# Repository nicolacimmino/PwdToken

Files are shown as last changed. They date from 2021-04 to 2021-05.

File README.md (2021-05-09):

# PwdToken

## Introduction

This started as a hardware implementation of a piece of paper with your password on it and, in some respect, it sill is. So use it with judgment! I toyed at first with the idea mostly of having something to type the WiFi password on new devices or for guests.

Once the novelty of the first quick implementation wore out, I started to wonder how I could make this at least reasonably secure. In its current incarnation the PwdToken offers the following features:

* Runs on a Digispark Digistump (or similart ATTiny85 device)
* Requires only 2 buttons to be soldered to the board
* Stores up to 4 passwords
* Emulates a USB keyboard and types the password
* Easy 2 buttons operation

Security features:
* Unlock password by morse keypad (optional)
* Unlock PIN by binary keypad (optional)
* Mechanism to validate count of boots and passwords recoveries (tamper/usage detection)

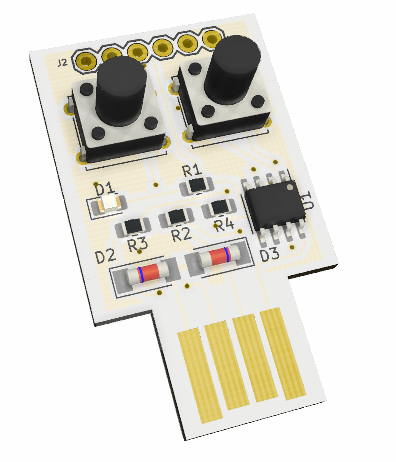
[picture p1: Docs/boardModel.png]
board


# Table of contents

[**Safety**](#safety)

&nbsp;&nbsp;&nbsp;&nbsp;[What makes this reasonably safe](#what-makes-this-reasonably-safe)<br>
&nbsp;&nbsp;&nbsp;&nbsp;[Known vulnerabilities](#known-vulnerabilities)<br>
&nbsp;&nbsp;&nbsp;&nbsp;[What can I do to make it safer?](#what-can-i-do-to-make-it-safer)<br>

[**Build one**](#build-one)

&nbsp;&nbsp;&nbsp;&nbsp;[The hardware](#the-hardware)<br>
&nbsp;&nbsp;&nbsp;&nbsp;[Special bootloader](#special-bootloader-optional)<br>

[**Usage**](#usage)

&nbsp;&nbsp;&nbsp;&nbsp;[Store passwords](#store-passwords)<br>
&nbsp;&nbsp;&nbsp;&nbsp;[Retrieve a password](#retrieve-a-password)<br>
&nbsp;&nbsp;&nbsp;&nbsp;[Getting the token banner](#getting-the-token-banner)<br>

[**Encase it**](#encase-it)

## Safety

Is it safe?

TLDR: **NO**

Long story. It can be reasonably safe depending on your use case. If you often need to log in on computers that are not yours and on which you can't run a password manager, this could be a viable option, especially if the alternative is to use a weak password that you can remember. At least you have shifted the extent of the potential attackers from anyone on the the Internet to anyone who can gain access to your token. 

### What makes this reasonably safe?

The passwords are stored in the actual application, and not in the data EEPROM. This means that if anyone attempts to replace the application with one that just exfiltrates the passwords then the passwords will actually be wiped.

There's a meachanism (optional) to keep track of the boots count and amount of times passwords have been retrieved. A command line application can be used to validate these against a manifest containing, among other information, a shared secret. While this doesn't prevent password theft it makes tampering evident.

### Known vulnerabilities

**do I need to say it? this is bound to be an incomplete list**

* An attacker could craft an .hex file that doesn't override the portion of code with the passwords and exfiltrates them. For this attack to be successfull it would be enough to compromise a host machine and have a microncleus uploader waiting for a device all the time (also the uploader would need to be made not to erase all memory before programming but just to send a page full of 0xFF on the part to override). This is an issue only if the stock micronucleus bootloader is used. This project provides a re-configured version of the bootloader that doesn't start unless button B (P0) is held. Additionally the special bootloader always erases user program on entry which prevents this attack also if the attacker has physical access to the token (assuming he cannot re-program it with an AVR programmer, ie that the board is encased in epoxy and only USB pins are accessible).

* An attacker could connect an AVR programmer and dump the application or replace the bootloader with one that exfiltrates the passwords. This is possible only if the attacker has physical access to the token. This can be mitigated by enclosing the devive in epoxy so that only the USB pins are accessible. While the attacker could still possibly re-program it, this would require access to the device for a longer time and the tampering would be evident.

* Because of the way the password lock works (just waits until the right PIN/Password is entered), and because the onboard LED signals the fact the token is locked, an attacker could build a device that brute forces the PIN/Password quite easily. One possible mitigating action would be to add a max errors after which the device wipes itself. Also in this case physical access to the device is needed to carry out this attack so epoxying the board would suffice.

### What can I do to make it safer?

* Make use of the provided modified bootloader so the device cannot be re-programmed without physical access to it and, even if bootloader is entered, the program is wiped already
* Don't store the full password, use a Horcrux (in a nutshell, make your password something like `fsnf23m!abcSomethingIOnlyKnow` and only store the `fsnf23m!abc` part to then type the reminder)
* Don't leave the token unattended and keep track of your tokens so you can immediately reset the passwords if one is missing
* Encase the device in epoxy so only the USB pins are accessible. This prevents PIN brute force automation as well as bootloaded replacement.

## Build one

### The hardware

If you want to just give this a spin a quick way to start is with a Digispark Digistump or another ATTiny85 board with USB. You will need to add two push buttons. Connect them between P0 and P2 and ground. See photo for one of my prototypes.

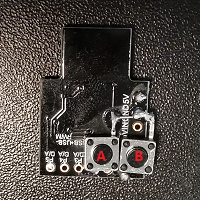
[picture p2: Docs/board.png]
board


If you feel instead like wire wrapping and you have a DIP ATTiny85 you can follow this schematic. J2 is needed only if you need to burn a bootloader, if your ATTiny is already loaded with a bootloader you can omit it.

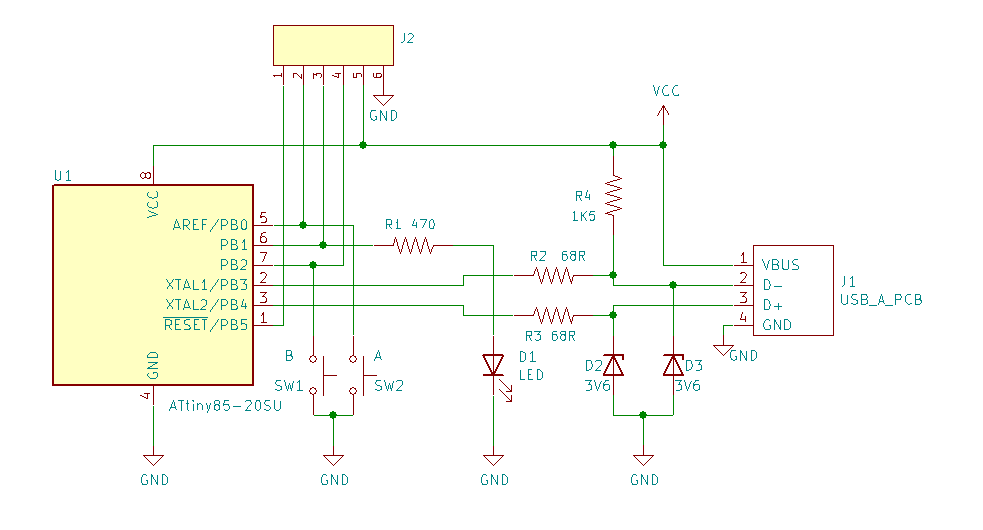
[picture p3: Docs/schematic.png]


Alternatively, if you really want to go serious you can find all the Kicad files for the board in the `Board` folder.

### Special bootloader (optional)

You can replace the standard "micronucleus" bootloader that comes with the Digistump and other ATTiny borards, with a version that doesn't wait in the bootloader by default when started. This makes your PwdToken immediately available when plugging it. Once you uploaded the re-configured bootloader you will need to pull P0 low (press button B before inserting the board in the USB port). To carry out this step you will need an ISP. I tested this with a USBASP. Others shouldn't be that much different but you will need to tweak the actual programming command. 

If you choose to skip this step the downside will be that once you plug your board in the USB port you will need to wait about 6 seconds for the bootloader to give up and your program to start.

Another tweak to the bootloader that can make the device safer, is to enable deletion of the user program as soon as it's  the bootloader is entered. In this way it won't be possible in any way to attempt to exfiltrate the passwords through USB. 

**NOTE**: it will be still possible to get to them if the attacker has access to all pins (device not epoxied) as he will be able to replace the bootloader.

See the readme in the "mirconucleus" folder below for instructions on building and flashing the special bootloader.

## Usage

### Store passwords 

**Without manifest**

If you wish to just set up passwords and don't want to generate a manifest to verify the integrity of the token (and to have proof the token has not been used) follow these simple steps:

* Copy `secrets_example.h` to `secrets.h` (this last is .gitignore:d so you don't risk to push your passwords!)
* Edit `secrets.h` and set your passwords and unlock password/pin if desired
* Edit `options.h` and set options as needed 
* Build and upload

**With manifest**

If you choose to generate a manifest for the token you will be able at a later time to verify that the token has not been tampered with and you will be able to determine if and how many times it has been booted and passwords have been retrieved.

To generate a manifest use the command line utility under `CommandLineTool\bin`:

* Run `pwdtoken gen`
* Choose a label for the token
* Choose a secret
* The utility will generate a manifest and store in clipboard
* Store the manifest somewhere safe (eg a password manager)
* The utility will also generate a `secrets.h` file
* Edit `secrets.h` and set your passwords and unlock password/pin if desired (don't change the OTP secret or the label though or you will invalidate the manifest!)
* Edit `options.h` and set options as needed 
* Build and upload

## Retrieve a Password

**note** the token emulates a standard US layout keyboard. You will need to make sure your keyboard layout matches, especially if your password contains symbols that might be mapped to different keys.

* Insert the token in a USB port and wait until the onboard red LED is solid red (or flashing slowly if you choose not to have an unlock PIN/Password)
* Type your PIN/Password if needed
* Once unlocked the onboard red LED will start to flash. The flashes count indicates the selected password
* Press repeatedly button B until the desired password is selected
* Focus on the application/field in which you need to type the password
* Press and hold A for more than 2 seconds and the password will by typed

## Getting the token banner

The token banner is a piece of formatted text that contains non-confidential information and can be used to validate the boot counts as well as to make sure your keyboard layout is correct. The banner is always accessible without unlocking the token. To print the banner follow these steps:

* Open a text editor and ensure it's in focus
* Insert the token while keeping button A pressed (make sure you don't confuse A with B if you have the special bootloader or your passwords will be lost!)
* Release the button as soon as the banner is starting to appear

A banner looks like this:

````
----------- begin -----------

; PwdToken 0.01-B
; Built Apr 14 2021 07:27:29
; Keyboard Layout US
; Hash Backslash: £ #
LBL: TST002
CBO: 3
CRE: 0
OTP: 3158792869

------------ end ------------
````

You can use the `; Hash Backslash: # \` line to validate that the current keyboard layout is correct. Most of the rest of the information in the banner is data needed by the command line utility to validate the boot and password retrieval counters.

## Encase it

In the `case` folder you will find a FreeCad project for a simple case for the token. This is suitable to be filled with epoxy to prevent (easy) access to the passwords through the ISP interface. There's no provision for screws or other fixing mechanisms, the two halves of the shell are meant to be glued together once the epoxy is set.

Top             |  Bottom    | Assembled
:-------------------------:|:-------------------------:|:-------------------------:
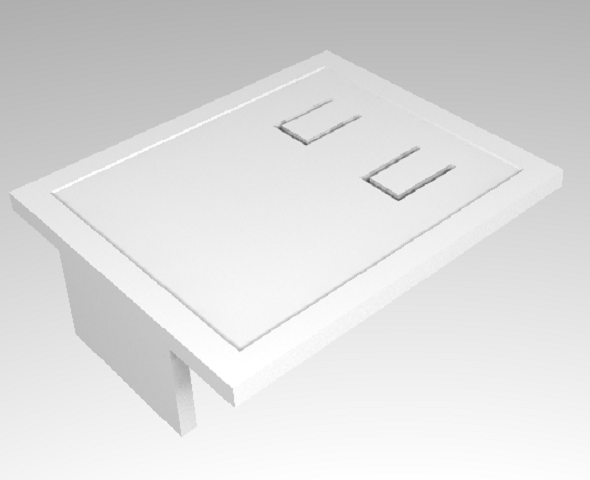
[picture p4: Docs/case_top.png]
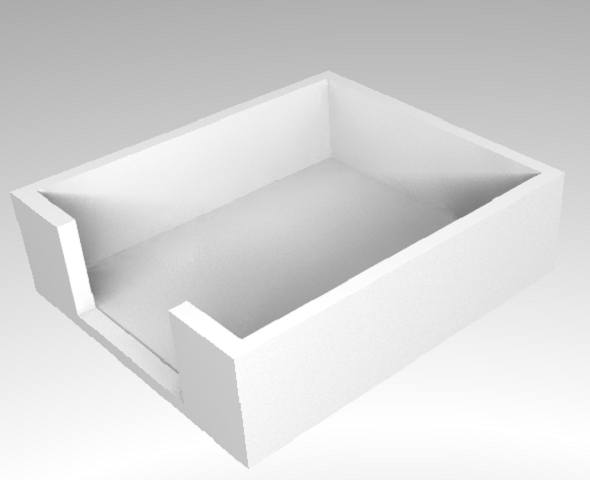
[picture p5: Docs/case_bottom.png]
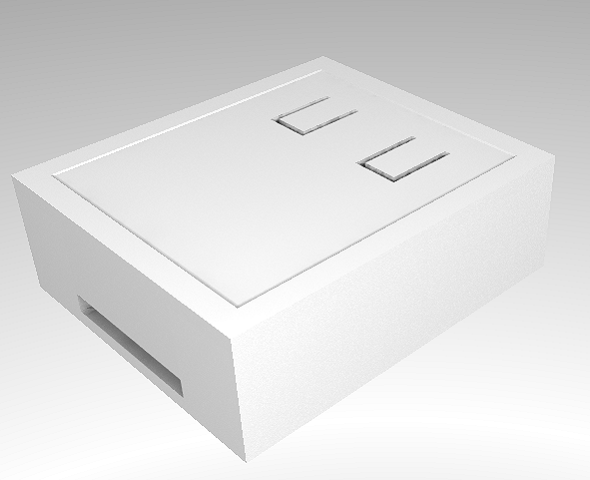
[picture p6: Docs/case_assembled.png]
  |   |

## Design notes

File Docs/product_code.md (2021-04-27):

0.1B

major: 0-9
.
minor: 0-9
keypad: B/M/N
-
hw rev: A-Z/a-z (PCB/wired)
month: 1-C
year: 1..9
bootloader: [-S]

0.1M-a41-S

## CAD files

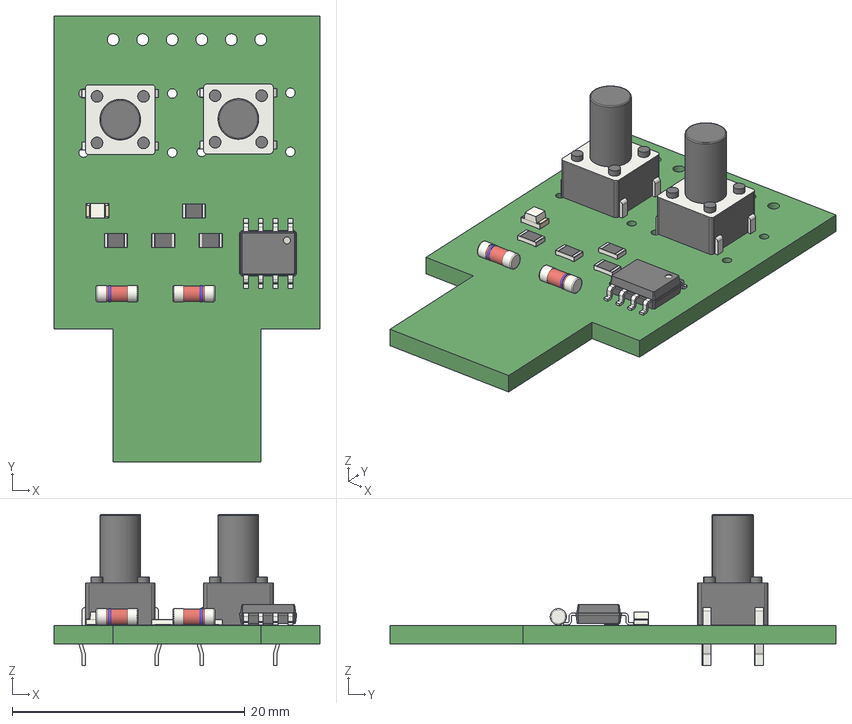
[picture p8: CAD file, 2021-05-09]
Board/PwdToken.step
22.9 x 38.4 x 13.0 mm

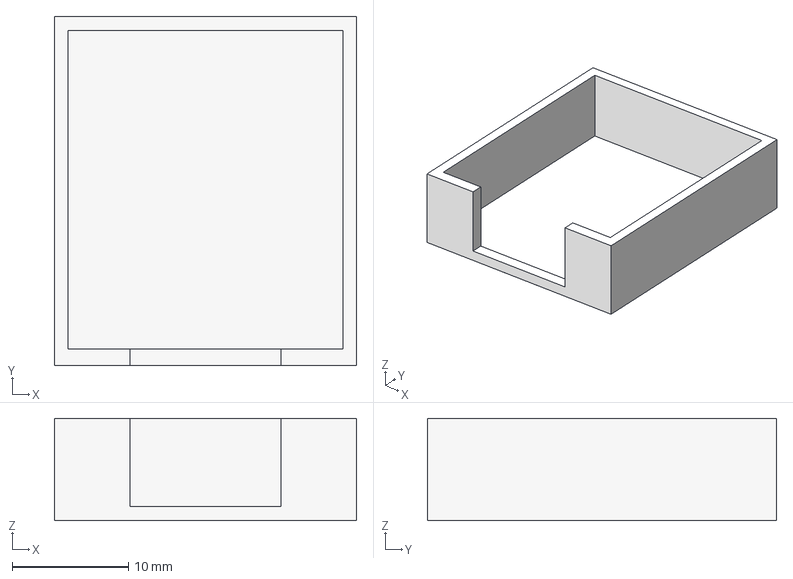
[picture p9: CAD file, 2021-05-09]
Case/PwdToken.FCStd
26.0 x 30.0 x 8.80 mm

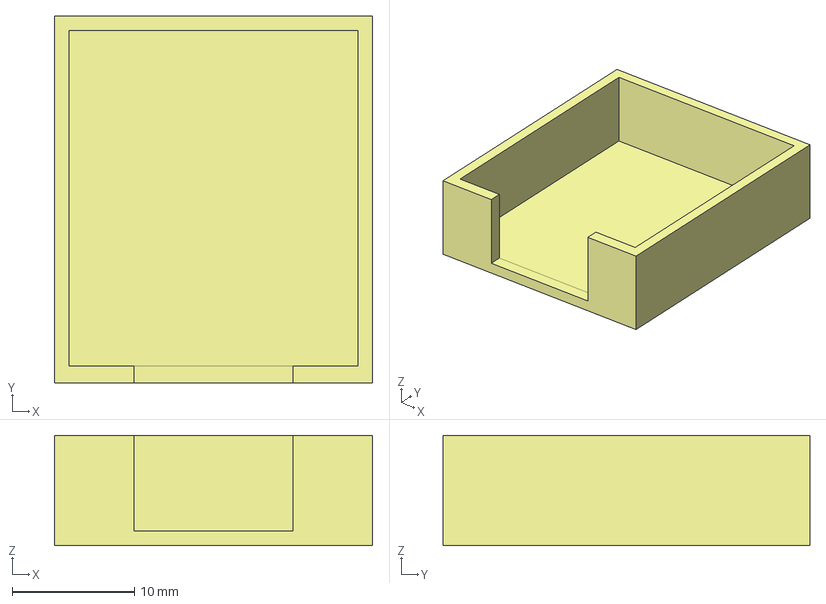
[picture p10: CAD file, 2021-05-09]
Case/PwdToken-Bottom.step
26.0 x 30.0 x 9.00 mm

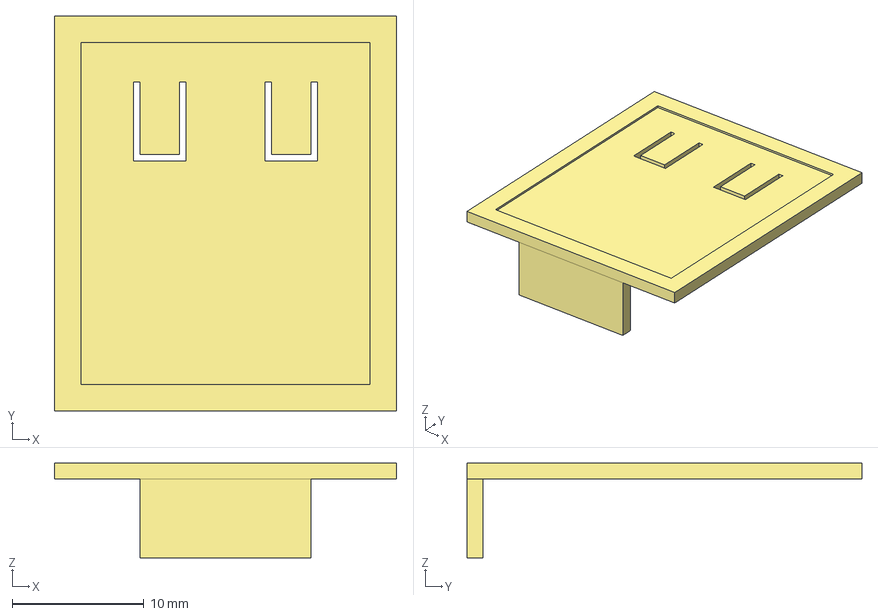
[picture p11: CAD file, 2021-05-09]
Case/PwdToken-Top.step
26.0 x 30.0 x 7.20 mm

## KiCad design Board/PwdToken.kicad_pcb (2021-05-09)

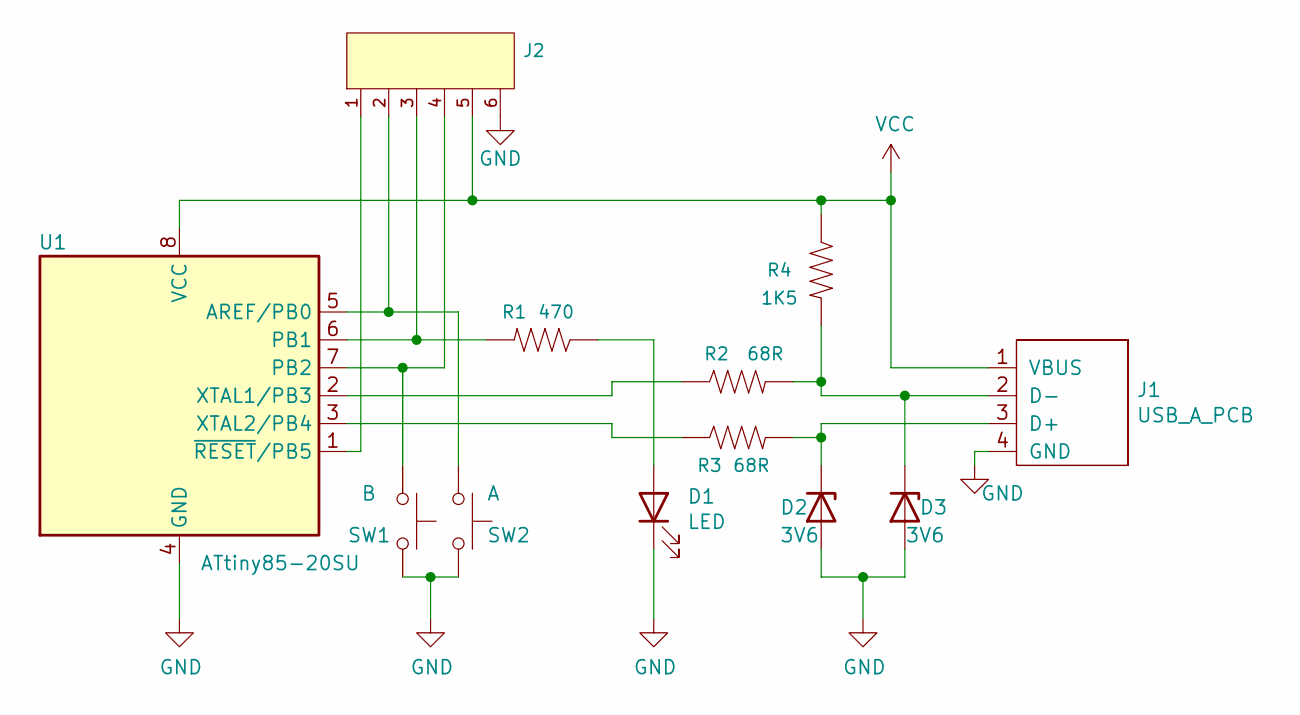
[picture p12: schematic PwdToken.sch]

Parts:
D1: LED; LED_0805_2012Metric_Pad1.15x1.40mm_HandSolder
D2, D3: 3V6; D_SOD-128
J1: USB_A_PCB; usb-PCB
J2: JST_6_PIN_VERTICAL; 1X06
R1: 470; R_0805_2012Metric_Pad1.20x1.40mm_HandSolder
R2, R3: 68R; R_0805_2012Metric_Pad1.20x1.40mm_HandSolder
R4: 1K5; R_0805_2012Metric_Pad1.20x1.40mm_HandSolder
SW1: A; SW_Tactile_Straight_KSA0Axx1LFTR
SW2: B; SW_Tactile_Straight_KSA0Axx1LFTR
U1: ATtiny85-20SU; SOIC-8_3.9x4.9mm_P1.27mm

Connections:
GND: D1.1 (K), D2.2 (A), D3.2 (A), J1.4 (GND), J2.6, SW1.2, SW2.2, U1.4 (GND)
unnamed: D1.2 (A), R1.1
unnamed: D2.1 (K), J1.3 (D+), R3.2
unnamed: D3.1 (K), J1.2 (D-), R2.2, R4.2
unnamed: J2.1, U1.1 (~RESET~/PB5)
unnamed: J2.2, SW2.1, U1.5 (AREF/PB0)
unnamed: J2.3, R1.2, U1.6 (PB1)
unnamed: J2.4, SW1.1, U1.7 (PB2)
unnamed: R2.1, U1.2 (XTAL1/PB3)
unnamed: R3.1, U1.3 (XTAL2/PB4)
VCC: J1.1 (VBUS), J2.5, R4.1, U1.8 (VCC)

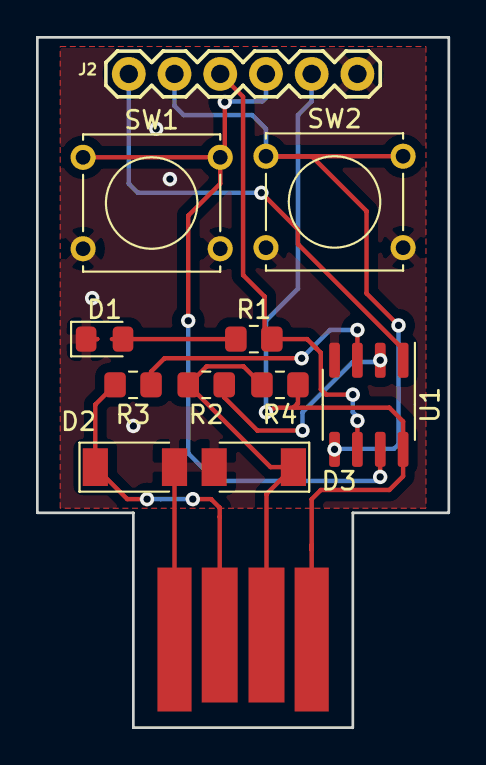
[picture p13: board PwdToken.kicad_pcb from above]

Board: 2 copper layers, 22.9 x 38.4 mm, 12 parts (0 on the bottom side), 11 nets.

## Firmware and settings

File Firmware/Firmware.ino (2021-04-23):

/****************************************************************************************************************************************************************
 *  PwdToken.
 *
 *  A hardware implementation of a piece of paper with your password, use with judgment!
 *
 *
 *  Copyright (C) 2021 Nicola Cimmino
 *
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
 *
 *  Copy  the contents of secrets_example.h into a new file secrets.h (this reduces the risk to push passwords to git as secrets.h is .gitignore:d
 */

#include <DigiKeyboard.h>
#include <EEPROM.h>
#include "options.h"
#include "src/config.h"
#include "secrets.h"
#include "src/secretGlobals.h"
#include "src/nbFlash.h"
#include "src/counters.h"
#include "src/banner.h"
#if UNLOCK_MODE == UNLOCK_MORSE_KEYBOARD
#include "src/morseKeyboard.h"
#elif UNLOCK_MODE == UNLOCK_BINARY_KEYBOARD
#include "src/binaryKeyboard.h"
#endif

uint8_t selectedPasswordIx = 0;

void setup()
{
  pinMode(PIN_LED_A, OUTPUT);
  digitalWrite(PIN_LED_A, LOW);

  pinMode(PIN_BUTTON_B, INPUT_PULLUP);
  pinMode(PIN_BUTTON_A, INPUT_PULLUP);

  DigiKeyboard.sendKeyStroke(0);

  // Press and hold Button B before reset to see the banner.
  if (digitalRead(PIN_BUTTON_A) == LOW)
  {
    DigiKeyboard.delay(500);

    Banner::print();

    while (true)
    {
      DigiKeyboard.delay(100);
    }
  }
}

void waitUnlockPassword()
{
#if UNLOCK_MODE == UNLOCK_NONE
  return;
#elif UNLOCK_MODE == UNLOCK_MORSE_KEYBOARD
  MorseKeyboard::waitForPassword();
#elif UNLOCK_MODE == UNLOCK_BINARY_KEYBOARD
  BinaryKeyboard::waitForPin();
#endif
}

void selectPassword()
{
  while (1)
  {
    while (digitalRead(PIN_BUTTON_B) == HIGH)
    {
      DigiKeyboard.delay(10);
      digitalWrite(PIN_LED_A, NBFlasher::flashCount(selectedPasswordIx, false));
    }

    digitalWrite(PIN_LED_A, LOW);

    DigiKeyboard.delay(100);

    unsigned long pressStart = millis();
    while (digitalRead(PIN_BUTTON_B) == LOW)
    {
      DigiKeyboard.delay(100);
      if (millis() - pressStart > 2000)
      {
        return;
      }
    }

    selectedPasswordIx = (selectedPasswordIx + 1) % PASWWORDS_COUNT;

    DigiKeyboard.delay(100);
  }
}

void typeSelectedPassword()
{
  Counters::incrementCounter(EEPROM_RETRIEVAL_COUNT);

  // Retrieve the password.
  char buffer[MAX_PWD_LEN];
  strcpy_P(buffer, (char *)pgm_read_word(&(passwords[selectedPasswordIx])));

  // Spit out the password.
  DigiKeyboard.print(buffer);

  // Wipe it from memory.
  memset(buffer, 0, MAX_PWD_LEN);
}

void loop()
{

  Counters::incrementCounter(EEPROM_BOOT_COUNT);

  waitUnlockPassword();

  while (1)
  {
    selectPassword();

    typeSelectedPassword();

    if (digitalRead(PIN_BUTTON_B) == LOW || digitalRead(PIN_BUTTON_A) == LOW)
    {
      DigiKeyboard.delay(100);
    }
  }
}

/*
 ****************************************************************************************************************************************************************/

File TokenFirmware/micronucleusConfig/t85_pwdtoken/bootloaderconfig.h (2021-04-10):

/* Name: bootloaderconfig.h
 * Micronucleus configuration file.
 * This file (together with some settings in Makefile.inc) configures the boot loader
 * according to the hardware.
 *
 * Controller type: ATtiny 85 - 16.5 MHz
 * Configuration:   Default configuration
 *       USB D- :   PB3
 *       USB D+ :   PB4
 *       Entry  :   Always
 *       LED    :   None
 *       OSCCAL :   Stays at 16 MHz
 * Note: Uses 16.5 MHz V-USB implementation with PLL
 * Last Change:     Jun 16,2020
 *
 * License: GNU GPL v2 (see License.txt
 */
#ifndef __bootloaderconfig_h_included__
#define __bootloaderconfig_h_included__

/* ------------------------------------------------------------------------- */
/*                       Hardware configuration.                             */
/*      Change this according to your CPU and USB configuration              */
/* ------------------------------------------------------------------------- */

#define USB_CFG_IOPORTNAME      B
  /* This is the port where the USB bus is connected. When you configure it to
   * "B", the registers PORTB, PINB and DDRB will be used.
   */

#define USB_CFG_DMINUS_BIT      3
/* This is the bit number in USB_CFG_IOPORT where the USB D- line is connected.
 * This may be any bit in the port.
 * USB- has a 1.5k pullup resistor to indicate a low-speed device.
 */
#define USB_CFG_DPLUS_BIT       4
/* This is the bit number in USB_CFG_IOPORT where the USB D+ line is connected.
 * This may be any bit in the port, but must be configured as a pin change interrupt.
 */

#define USB_CFG_CLOCK_KHZ       (F_CPU/1000)
/* Clock rate of the AVR in kHz. Legal values are 12000, 12800, 15000, 16000,
 * 16500, 18000 and 20000. The 12.8 MHz and 16.5 MHz versions of the code
 * require no crystal, they tolerate +/- 1% deviation from the nominal
 * frequency. All other rates require a precision of 2000 ppm and thus a
 * crystal!
 * Since F_CPU should be defined to your actual clock rate anyway, you should
 * not need to modify this setting.
 */

/* ----------------------- Optional Hardware Config ------------------------ */
//#define USB_CFG_PULLUP_IOPORTNAME   B
/* If you connect the 1.5k pullup resistor from D- to a port pin instead of
 * V+, you can connect and disconnect the device from firmware by calling
 * the macros usbDeviceConnect() and usbDeviceDisconnect() (see usbdrv.h).
 * This constant defines the port on which the pullup resistor is connected.
 */
//#define USB_CFG_PULLUP_BIT          0
/* This constant defines the bit number in USB_CFG_PULLUP_IOPORT (defined
 * above) where the 1.5k pullup resistor is connected. See description
 * above for details.
 */

/* ------------- Set up interrupt configuration (CPU specific) --------------   */
/* The register names change quite a bit in the ATtiny family. Pay attention    */
/* to the manual. Note that the interrupt flag system is still used even though */
/* interrupts are disabled. So this has to be configured correctly.             */

// setup interrupt for Pin Change for D+
#define USB_INTR_CFG            PCMSK // Pin interrupt enable register
#define USB_INTR_CFG_SET        (1 << USB_CFG_DPLUS_BIT) // Mask for pin in pin interrupt enable register PCMSK to be set on usbInit
#define USB_INTR_CFG_CLR        0 // Mask for pin in pin interrupt enable register PCMSK to be cleared on usbInit. 0 = no clear
#define USB_INTR_ENABLE         GIMSK // Global interrupt enable register
#define USB_INTR_ENABLE_BIT     PCIE  // Bit position in global interrupt enable register
#define USB_INTR_PENDING        GIFR  // Register to read interrupt flag
#define USB_INTR_PENDING_BIT    PCIF  // Bit position in register to read interrupt flag

/* ------------------------------------------------------------------------- */
/*       Configuration relevant to the CPU the bootloader is running on      */
/* ------------------------------------------------------------------------- */

// how many milliseconds should host wait till it sends another erase or write?
// needs to be above 4.5 (and a whole integer) as avr freezes maximum for 4.5ms
// while writing a FLASH page (even for 128 byte page size:-))
#define MICRONUCLEUS_WRITE_SLEEP 5


/* ---------------------- feature / code size options ---------------------- */
/*               Configure the behavior of the bootloader here               */
/* ------------------------------------------------------------------------- */
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

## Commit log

2021-03-20 Refactor, don't always print banner
2021-03-20 Add LED
2021-04-02 Flash current password index
2021-04-10 Bettwer hw config and button B added
2021-04-12 Add some delay before printing the banner
2021-04-12 Swap A/B naming, keep same pins, makes more sense when looking at the device plugged in
    [Firmware.ino, config.h]
2021-04-14 Update samples
2021-04-21 Add failed logins counter
    [config.h]
2021-04-22 Add unlock reset count
    [Firmware.ino, config.h]
2021-04-23 Self destruct on max failed login exceeded
    [Firmware.ino]
2021-04-24 Add board
    [PwdToken-B_Cu.gbr, PwdToken-B_Mask.gbr, PwdToken-B_SilkS.gbr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]
2021-04-25 Add model render
    [PwdToken.kicad_pcb]
2021-04-25 Update to white board
    [PwdToken.kicad_pcb]
2021-04-26 Add schematic
    [PwdToken.sch]
2021-05-09 Add case
    [PwdToken-Bottom.step, PwdToken-Top.step, PwdToken.FCStd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]
2021-05-09 Better renders
    [PwdToken.FCStd]
2021-05-09 Make all images same size
    [PwdToken.FCStd]
2021-05-09 Fix board USB connector size
    [PwdToken.kicad_pcb]

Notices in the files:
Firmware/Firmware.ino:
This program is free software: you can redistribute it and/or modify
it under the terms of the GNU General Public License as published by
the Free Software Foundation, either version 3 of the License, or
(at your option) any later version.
